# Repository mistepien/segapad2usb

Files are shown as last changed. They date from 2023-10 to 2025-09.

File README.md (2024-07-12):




# segapad2usb
Sega MD/Genesis gampepad adapter to USB.

<a href="https://github.com/mistepien/segapad2usb/blob/main/segapad2usb.pdf">Adapter</a> is actually a shield for 
<a href="https://learn.sparkfun.com/tutorials/pro-micro--fio-v3-hookup-guide/hardware-overview-pro-micro">Arduino Pro Micro based on ATmega 32U4</a>.

ATmega 32U4 has a hardware support for fullspeed USB, thus <a href="https://wiki.archlinux.org/title/mouse_polling_rate">polling rate 1000Hz</a> is not an issue for that chip.

You can use the <a href="https://github.com/mistepien/segapad2usb/tree/main/production">gerber file<a> to order the PCB.

Attached <a href="https://github.com/mistepien/segapad2usb/tree/main/firmware">code</a> uses port registers so that is quite efficient. The code is based on <a href="https://github.com/jonthysell/SegaController">SegaController library</a>. That library was changed to use port registers and support HOME button. The code was tested with <a href="https://www.8bitdo.com/m30-2-4g/">M30 2.4G for SEGA Genesis & Mega Drive</a> and <a href="https://retro-bit.com/sega-genesis-6-button-arcade-pad-black.html">SEGA Genesis 6-button Arcade Pad</a>. <a href="https://www.8bitdo.com/m30-2-4g/">M30 2.4G for SEGA Genesis & Mega Drive</a> has a HOME button and it is fully supported by the code.

One footprint is not trivial: DB9 male socket (<b>J1</b>). Officialy the <b>J1</b> footprint (segapad2usb has been designed in <a href="https://www.kicad.org/">KiCad</a>) is "DSUB-9_Male_Horizontal_P2.77x2.84mm_EdgePinOffset9.90mm_Housed_MountingHolesOffset11.32mm" however it was chosen to fit <a href="https://www.tme.eu/pl/en/details/ld09p13a4gx00lf/d-sub-plugs-and-sockets/amphenol-communications-solutions/">LD09P13A4GX00LF Amphenol</a>.

<b>J2</b> is redundant -- you can use it to add some new features like autofire switch or sth.

Sometimes during uploading code to Arduino board you may face some issues -- then you will need to use RESET -- so <b>SW1</b> can be useful if you like to develope your own code.

SW2 can be usefull to have a so-called "Hot key" -- you can need it eg. in Batocera.

LED D1 shows whether controller is working in 6-button mode. LED D2 shows is Sega MD/Genesis gampepad connected at all. LED D3 show status of Arduino (turn on in setup() function of firmware).

BOM:
| Qty	| Reference(s) | Description |
|-----|---|---|
|2 | D1, D2, D3 | LEDs 3mm |  
|1 |	J1|	DB9 Male Connector <a href="https://www.tme.eu/pl/en/details/ld09p13a4gx00lf/d-sub-plugs-and-sockets/amphenol-communications-solutions/">LD09P13A4GX00LF Amphenol</a> |
|1 |	J2|	2x4 Pinheader. pitch terminal: 2.54mm |
|1 | R1, R2. R3 | resistors for D1, D2 and D3 |
|1 | SW1,SW2 | Tact switches from Arduino breadboard projects |
|1 | U1 |	DIP20 socket (width 15.24mm) + <a href="https://learn.sparkfun.com/tutorials/pro-micro--fio-v3-hookup-guide/hardware-overview-pro-micro">Arduino Pro Micro</a> |

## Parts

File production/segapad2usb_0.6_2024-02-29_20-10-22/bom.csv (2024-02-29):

Designator | Footprint | Quantity | Value | LCSC Part #
D1 | LED_D3.0mm_Oval | 1 | CTL-ON
D2 | LED_D3.0mm_Oval | 1 | 6BTN MODE
D3 | LED_D3.0mm_Oval | 1 | STATUS
J1 | DSUB-9_Male_Horizontal_P2.77x2.84mm_EdgePinOffset9.90mm_Housed_OVAL_MountingHolesOffset11.32mm | 1 | DB9_MALE_SEGA
J2 | PinHeader_2x04_P2.54mm_Vertical | 1 | Conn_02x04_Odd_Even
R1, R2, R3 | R_Axial_DIN0207_L6.3mm_D2.5mm_P10.16mm_Horizontal_Oval | 3 | RxΩ
SW1 | SW_PUSH_6mm_H4.3mm | 1 | RST
SW2 | SW_PUSH_6mm_H4.3mm | 1 | HOT KEY
U1 | DIP-24_W15.24mm_Socket_LongPads | 1 | Arduino_Pro_Micro

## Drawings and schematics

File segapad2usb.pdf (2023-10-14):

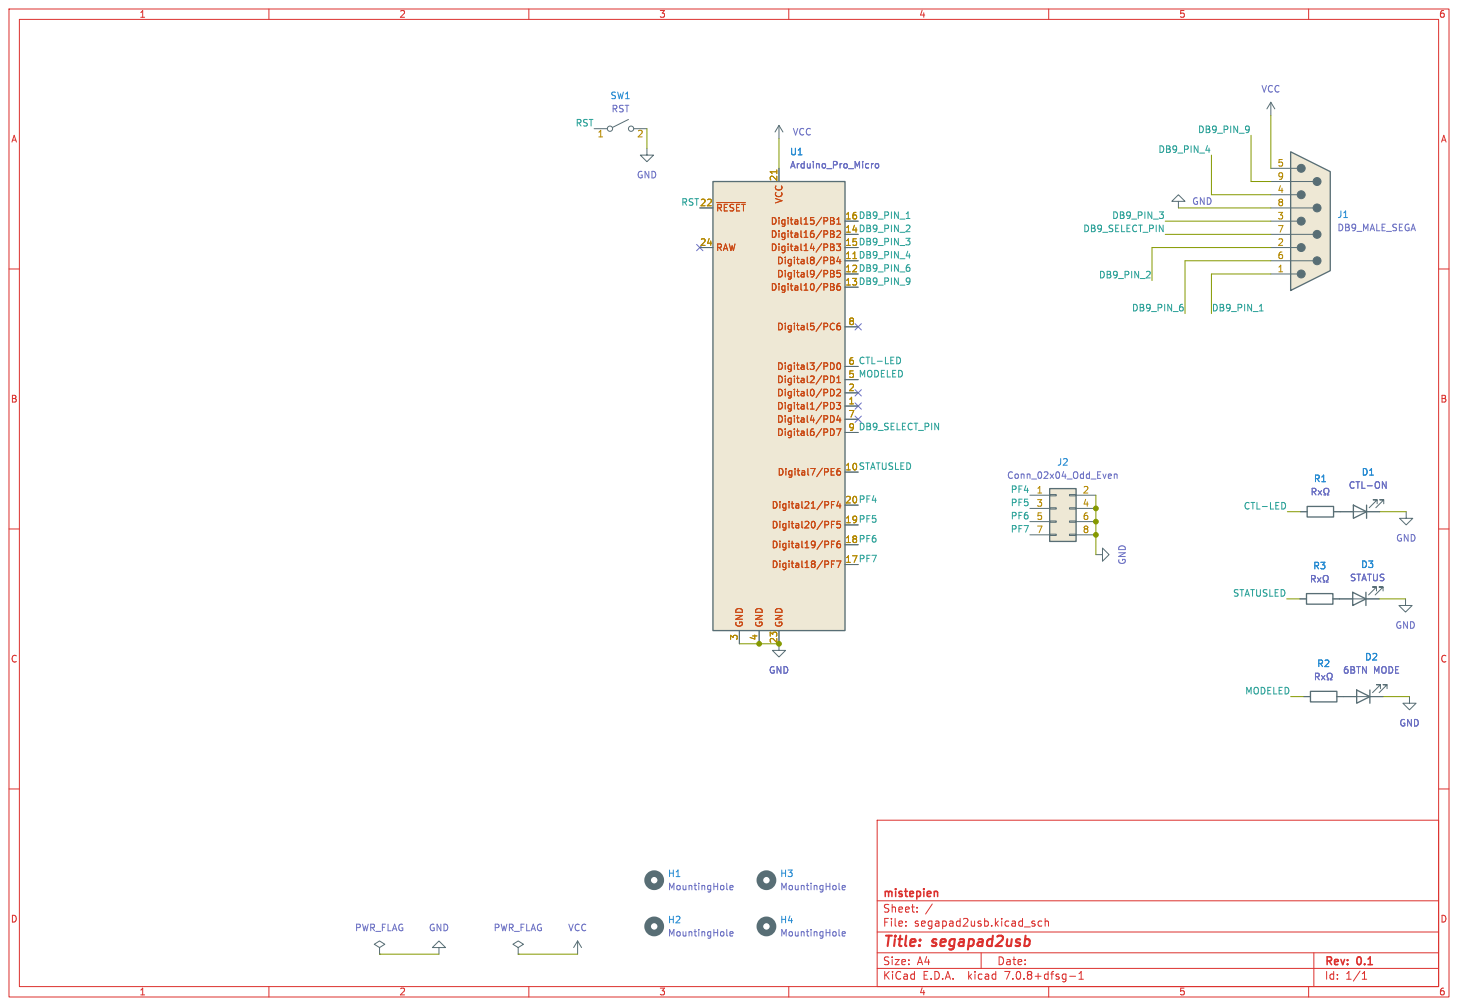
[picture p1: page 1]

File: segapad2usb.kicad_sch Sheet: / mistepien GND

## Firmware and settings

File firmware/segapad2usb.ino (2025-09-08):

//
// segapad2usb.ino
// Author: mistepien@wp.pl
// Copyright 2023
//
// Based on https://github.com/jonthysell/SegaController
//
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

/* "PINOUT" of gamepad's output

  0    SC_CTL_ON    = 1, // The controller is connected
  1    SC_MODE      = 2, //checking six or three mode
  2    SC_BTN_START = 4,
  3    SC_BTN_UP    = 8,
  4    SC_BTN_DOWN  = 16,
  5    SC_BTN_LEFT  = 32,
  6    SC_BTN_RIGHT = 64,
  7    SC_BTN_A     = 128,
  8    SC_BTN_B     = 256,
  9    SC_BTN_C     = 512,
  10   SC_BTN_X     = 1024,
  11   SC_BTN_Y     = 2048,
  12   SC_BTN_Z     = 4096,
  13   SC_BTN_HOME  = 8192 //availabe in M30 2.4 8Bitdo gamepad
*/


#include "SegaController.h"

#include <Joystick.h>  //https://github.com/MHeironimus/ArduinoJoystickLibrary
Joystick_ Joystick(JOYSTICK_DEFAULT_REPORT_ID, JOYSTICK_TYPE_JOYSTICK,
                   8, 0,                  // Button Count, Hat Switch Count
                   true, true, false,     // X and Y, but no Z Axis
                   false, false, false,   // No Rx, Ry, or Rz
                   false, false,          // No rudder or throttle
                   false, false, false);  // No accelerator, brake, or steering

void setup() {
  bitSet(DDRD, 0);  //bitClear(PORTD, 0); //CTL-ON LED - OFF
  bitSet(DDRD, 1);  //bitClear(PORTD, 1); //MODE LED - OFF
  bitSet(DDRE, 6);  //bitClear(PORTE, 6); //STATUS LED - OFF

  sega.begin(7, 1, 2, 3, 4, 5, 6);

  Joystick.setXAxisRange(-1, 1);
  Joystick.setYAxisRange(-1, 1);
  Joystick.begin(false);
  Joystick.setXAxis(0);
  Joystick.setYAxis(0);

  delay(1500); /*very ugly and dirty hack
                without that delay() joystick will not
                be centered at the beginning (that is an
                issue with Joystick.sendState();
*/


  /*turn off RX and TX LEDS on permanent basis

     turning off these LEDS here at the end of setup()
     is an indicator that segapad2usb is ready
  */
  bitClear(DDRD, 5);
  bitClear(DDRB, 0);

  Joystick.sendState();

  bitSet(PORTE, 6);  //STATUS LED - ON
}

byte DPAD_UP;
byte DPAD_DOWN;
byte DPAD_LEFT;
byte DPAD_RIGHT;

void button(byte btn, bool btn_state) {
  switch (btn) {
    case SC_CTL_ON:
      bitWrite(PORTD, 0, btn_state);  //CTL-ON
      break;
    case SC_MODE:
      bitWrite(PORTD, 1, btn_state);  //6BTN-MODE
      break;
    case SC_BTN_START:
      Joystick.setButton(0, btn_state);  //BTN START
      break;
    case SC_DPAD_UP:
      DPAD_UP = btn_state;
      break;
    case SC_DPAD_DOWN:
      DPAD_DOWN = btn_state;
      break;
    case SC_DPAD_LEFT:
      DPAD_LEFT = btn_state;
      break;
    case SC_DPAD_RIGHT:
      DPAD_RIGHT = btn_state;
      break;
    case SC_BTN_A:
      Joystick.setButton(1, btn_state);  //BTN A
      break;
    case SC_BTN_B:
      Joystick.setButton(2, btn_state);  //BTN B
      break;
    case SC_BTN_C:
      Joystick.setButton(3, btn_state);  //BTN C
      break;
    case SC_BTN_X:
      Joystick.setButton(4, btn_state);  //BTN X
      break;
    case SC_BTN_Y:
      Joystick.setButton(5, btn_state);  //BTN Y
      break;
    case SC_BTN_Z:
      Joystick.setButton(6, btn_state);  //BTN Z
      break;
    case SC_BTN_HOME:
      Joystick.setButton(7, btn_state);  //BTN HOME //ONLY M30 8Bitdo
      break;
  }
}

word current_state = 0;
word prev_state = 0;

void send_state() {
  bitClear(current_state, SC_BTN_MODE);
  /* clear SC_BTN_MODE would trigger
   the routine but we are not interested
   in SC_BTN_MODE at all
*/

  word changed_state = prev_state ^ current_state;
  if (changed_state) {
    prev_state = current_state;
    for (byte index = 0; index < 15; index++) {
      if (changed_state & 1) {
        button(index, current_state & 1);
      }
      changed_state >>= 1;
      current_state >>= 1;
    }

    Joystick.setYAxis(DPAD_DOWN - DPAD_UP);
    Joystick.setXAxis(DPAD_RIGHT - DPAD_LEFT);
  }
  Joystick.sendState();  //ONE common send.State for AXISES AND BUTTONS
}


void loop() {
  while (1) {  //https://arduino.stackexchange.com/questions/337/would-an-infinite-loop-inside-loop-perform-faster
    current_state = sega.getState();
    send_state();
  }
}

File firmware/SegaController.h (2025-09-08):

// Author:
//       Michał Stępień <mistepien@wp.pl>
//
// Copyright (c) 2025 Michał Stępień <mistepien@wp.pl>
//
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
// THE SOFTWARE IS PROVIDED "AS IS", WITHOUT WARRANTY OF ANY KIND, EXPRESS OR
// IMPLIED, INCLUDING BUT NOT LIMITED TO THE WARRANTIES OF MERCHANTABILITY,
// FITNESS FOR A PARTICULAR PURPOSE AND NONINFRINGEMENT. IN NO EVENT SHALL THE
// AUTHORS OR COPYRIGHT HOLDERS BE LIABLE FOR ANY CLAIM, DAMAGES OR OTHER
// LIABILITY, WHETHER IN AN ACTION OF CONTRACT, TORT OR OTHERWISE, ARISING FROM,
// OUT OF OR IN CONNECTION WITH THE SOFTWARE OR THE USE OR OTHER DEALINGS IN
// THE SOFTWARE.
#if defined(ARDUINO_AVR_MICRO)

#define DDR_REG_select_Pin DDRD
#define PORT_REG_selectPin PORTD
#define PIN_REG_selectPin PIND

#define DDR_REG_inputPins DDRB
#define PORT_REG_inputPins PORTB
#define PIN_REG_inputPins PINB

#else

#define DDR_REG_select_Pin DDRD
#define PORT_REG_selectPin PORTD
#define PIN_REG_selectPin PIND

#define DDR_REG_inputPins DDRD
#define PORT_REG_inputPins PORTD
#define PIN_REG_inputPins PIND

#endif

enum sega_state {
  SC_CTL_ON = 0,  // The controller is connected
  SC_MODE = 1,    //checking six or three mode 1
  SC_BTN_START = 2,
  SC_DPAD_UP = 3,
  SC_DPAD_DOWN = 4,
  SC_DPAD_LEFT = 5,
  SC_DPAD_RIGHT = 6,
  SC_BTN_A = 7,
  SC_BTN_B = 8,
  SC_BTN_C = 9,
  SC_BTN_X = 10,
  SC_BTN_Y = 11,
  SC_BTN_Z = 12,
  SC_BTN_MODE = 13,
  SC_BTN_HOME = 14  //availabe in M30 2.4 8Bitdo gamepad
};

typedef struct {
  byte _cycle;
  byte _ipin_first;
  byte _ipin_second;
  word _output_bit;
} regs_to_state_struct;

constexpr regs_to_state_struct regs_to_cycle[] = { { 2, 2, 3, bit(SC_CTL_ON) },
                                                   { 2, 4, 4, bit(SC_BTN_A) },
                                                   { 2, 5, 5, bit(SC_BTN_START) },
                                                   { 3, 0, 0, bit(SC_DPAD_UP) },
                                                   { 3, 1, 1, bit(SC_DPAD_DOWN) },
                                                   { 3, 2, 2, bit(SC_DPAD_LEFT) },
                                                   { 3, 3, 3, bit(SC_DPAD_RIGHT) },
                                                   { 3, 4, 4, bit(SC_BTN_B) },
                                                   { 3, 5, 5, bit(SC_BTN_C) },
                                                   { 4, 0, 1, bit(SC_MODE) },
                                                   { 5, 0, 0, bit(SC_BTN_Z) },
                                                   { 5, 1, 1, bit(SC_BTN_Y) },
                                                   { 5, 2, 2, bit(SC_BTN_X) },
                                                   { 5, 3, 3, bit(SC_BTN_MODE) },
                                                   { 6, 0, 0, bit(SC_BTN_HOME) } };

constexpr word three_mode_buttons = bit(SC_CTL_ON) | bit(SC_BTN_START) | bit(SC_DPAD_UP) | bit(SC_DPAD_DOWN) | bit(SC_DPAD_LEFT) | bit(SC_DPAD_RIGHT) | bit(SC_BTN_A) | bit(SC_BTN_B) | bit(SC_BTN_C);

constexpr byte SC_INPUT_PINS = 6;

#define SC_READ_DELAY_MS 0  // Must be >= 3ms to give 6-button controller time to reset

// Delay (µs) between setting the select pin and reading the button pins
#if defined(ARDUINO_AVR_MICRO)
constexpr unsigned long SC_CYCLE_DELAY_US = 6;
#elif (F_CPU == 3686400L) || (F_CPU == 3276800L) || (F_CPU == 2000000L)
constexpr unsigned long SC_CYCLE_DELAY_US = 3;
#elif (F_CPU == 4000000L)
constexpr unsigned long SC_CYCLE_DELAY_US = 4;  //4MHz: 0..5 -- retrobit,   0..20 - 8bido M30 2.4, 0..100 - chinesse no-name
#elif (F_CPU == 6000000L) || (F_CPU == 7372800L) || (F_CPU == 8000000L)
constexpr unsigned long SC_CYCLE_DELAY_US = 7;  //6MHz: 4..11 --retrobit, 7.3728MHz: 0..15 -- retrobit, 8MHZ: 0..13 -- retrobit
#elif (F_CPU == 11059200L) || (F_CPU == 16000000L) || (F_CPU == 12000000L) || (F_CPU == 14745600)
constexpr unsigned long SC_CYCLE_DELAY_US = 10;  //11.0592MHz: 3..18 -- retrobit, 16MHz: 0..17 -- retrobit
#endif

class SegaController {
public:
  void begin(byte db9_pin_7, byte db9_pin_1, byte db9_pin_2, byte db9_pin_3, byte db9_pin_4, byte db9_pin_6, byte db9_pin_9);
  word getState();
  bool complex_bool_value(byte big_byte, byte tested_byte);
private:
  byte _selectPin_bin;  // output select pin useful for HARDWARE XOR
  byte _inputPins[];
  word nod(word _input_state, word _dpad_dirs);
};

extern SegaController sega;

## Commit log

2023-10-14 PCB Rev. 0.4
    - GND zone on both sides of pcb
    - status led
    [segapad2usb.kicad_pcb, segapad2usb.kicad_sch]
2023-10-14 status led added
2023-10-14 PCB Rev. 0.5
    pcb will be cheaper in JLCPCB
    [segapad2usb.kicad_pcb]
2024-02-29 added teardrops
    [bom.csv, designators.csv, positions.csv]
2025-09-08 new version of sega controller library
    huge switch case is removed -- code is shorter
    [SegaController.h, segapad2usb.ino]
